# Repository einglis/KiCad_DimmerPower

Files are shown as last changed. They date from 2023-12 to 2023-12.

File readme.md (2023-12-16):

# Dimmer Power Board

A power board for my lounge dimmer project.  Ultimately driven by an Arduino running code in https://github.com/einglis/dimmer.  (And a RaspberyPI providing a UI, and another Arduino receiving Rako wireless commands, both also running code from the same repo.)

Originally based on https://www.instructables.com/Multichannel-Wireless-Light-Dimmer/

At the time of writing, the six live boards have got 5 years of successful operation under their belts.

## Version History
I drew this originally in Eagle, but the committed project is for KiCad.  KiCad seemed to import it just fine and the schematic and board layout look identical to the production parts; the gerbers in the `output/` folder check out too.

All the same, I preserved the bulk of the Eagle files in the `retired/` folder, just in case.  They show signs of sequential-numbering version control...

## Pictures
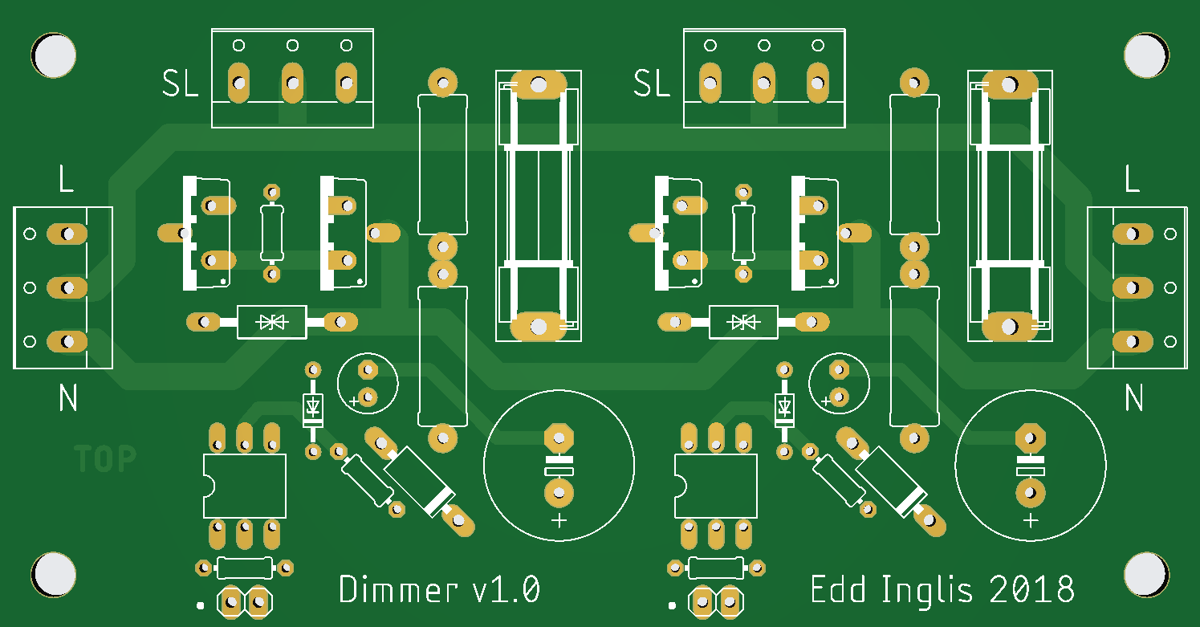
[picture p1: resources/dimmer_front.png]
front

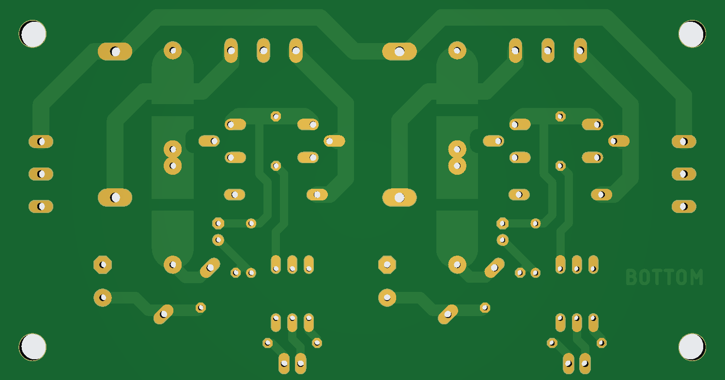
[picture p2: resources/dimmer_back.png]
back


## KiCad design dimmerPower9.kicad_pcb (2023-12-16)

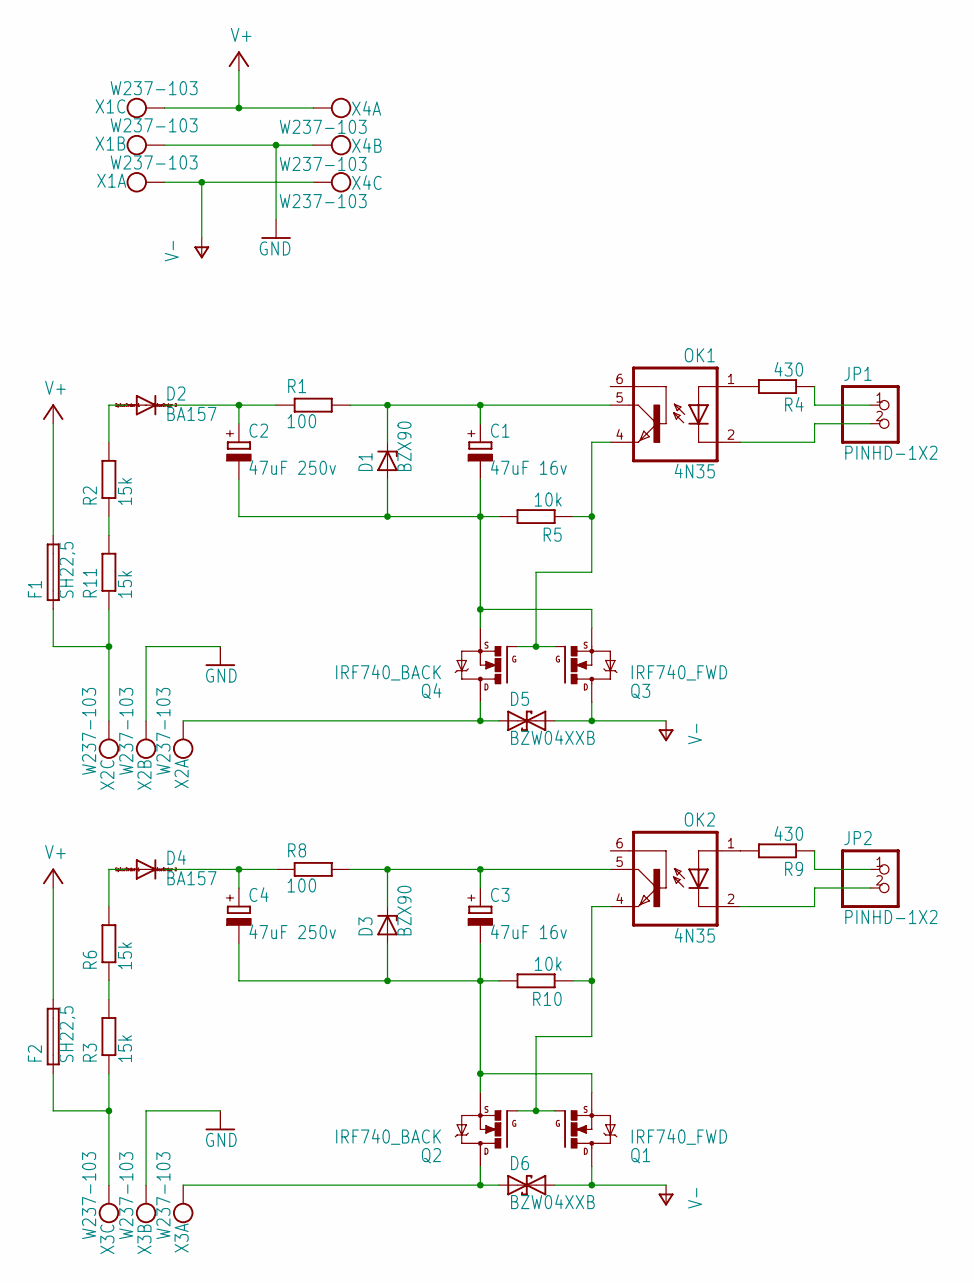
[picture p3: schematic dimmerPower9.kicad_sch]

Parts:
C1, C3: 47uF 16v; E2,5-6
C2, C4: 47uF 250v; E5-13
D1, D3: BZX90; DO34Z7
D2, D4: BA157; P1-10
D5, D6: BZW04XXB; F126Z12
F1, F2: SH22,5
JP1, JP2: PINHD-1X2; 1X02
OK1, OK2: 4N35; DIL06
Q1, Q3: IRF740_FWD; TO220BV_FWD
Q2, Q4: IRF740_BACK; TO220BV_BACK
R1, R8: 100; 0204_7
R2, R3, R6, R11: 15k; P0613_15
R4, R9: 430; 0204_7
R5, R10: 10k; 0204_7
X1, X2, X3, X4: W237-103

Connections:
GND: X1.2, X2.2, X3.2, X4.2
unnamed: C1.-, C2.-, D1.A, Q3.S, Q4.S, R5.2
unnamed: JP1.1, R4.1
unnamed: OK1.1 (A), R4.2
unnamed: JP1.2, OK1.2 (C)
unnamed: F1.1, R11.1, X2.3
unnamed: R3.2, R6.1
unnamed: R2.1, R11.2
unnamed: D2.A, R2.2
unnamed: C2.+, D2.C, R1.1
unnamed: C1.+, D1.C, OK1.5 (COL), R1.2
unnamed: OK1.4 (EMI), Q3.G, Q4.G, R5.1
unnamed: D5.A (1), Q4.D, X2.1
unnamed: D4.A, R6.2
unnamed: C4.+, D4.C, R8.1
unnamed: C3.+, D3.C, OK2.5 (COL), R8.2
unnamed: OK2.1 (A), R9.2
unnamed: D6.A (1), Q2.D, X3.1
unnamed: JP2.1, R9.1
unnamed: JP2.2, OK2.2 (C)
unnamed: OK2.4 (EMI), Q1.G, Q2.G, R10.1
unnamed: C3.-, C4.-, D3.A, Q1.S, Q2.S, R10.2
unnamed: F2.1, R3.1, X3.3
V+: F1.2, F2.2, X1.3, X4.1
V-: D5.C (2), D6.C (2), Q1.D, Q3.D, X1.1, X4.3

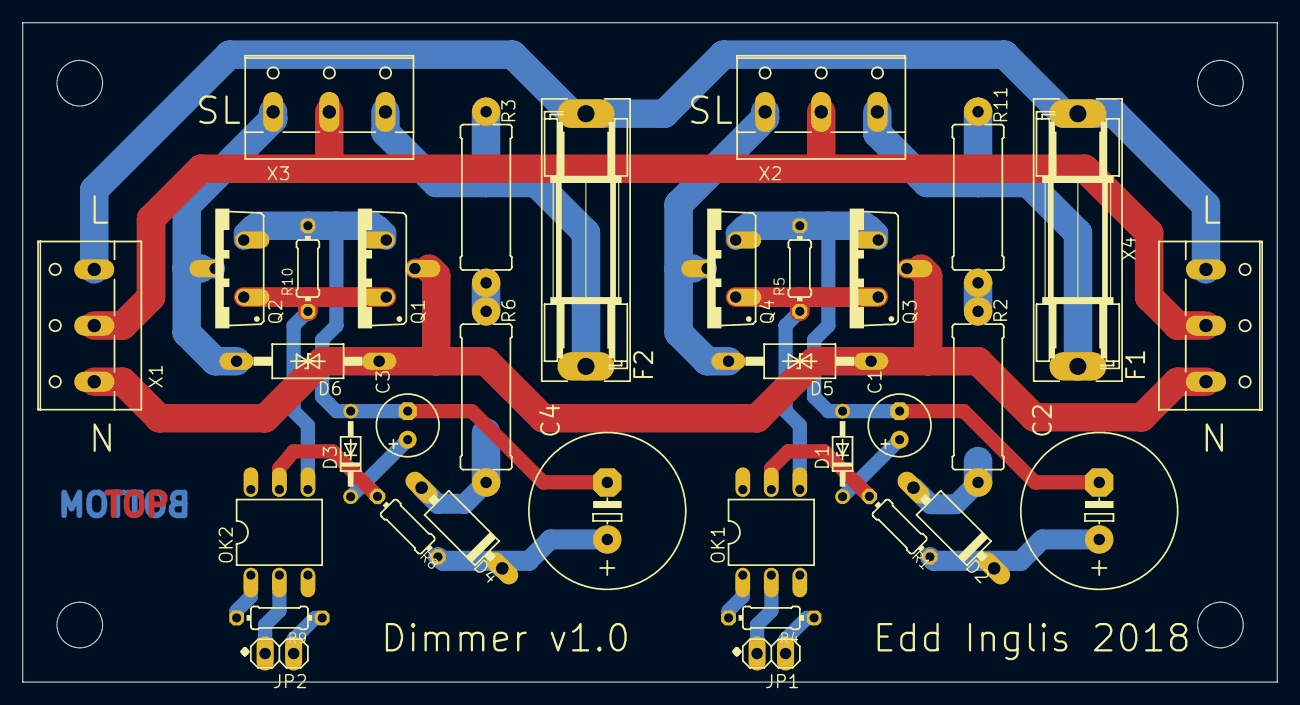
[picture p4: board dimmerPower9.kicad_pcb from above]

Board: 4 copper layers, 111.7 x 58.7 mm, 38 parts (0 on the bottom side), 25 nets.

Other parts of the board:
@HOLE0, @HOLE1, @HOLE2, @HOLE3: (no value)

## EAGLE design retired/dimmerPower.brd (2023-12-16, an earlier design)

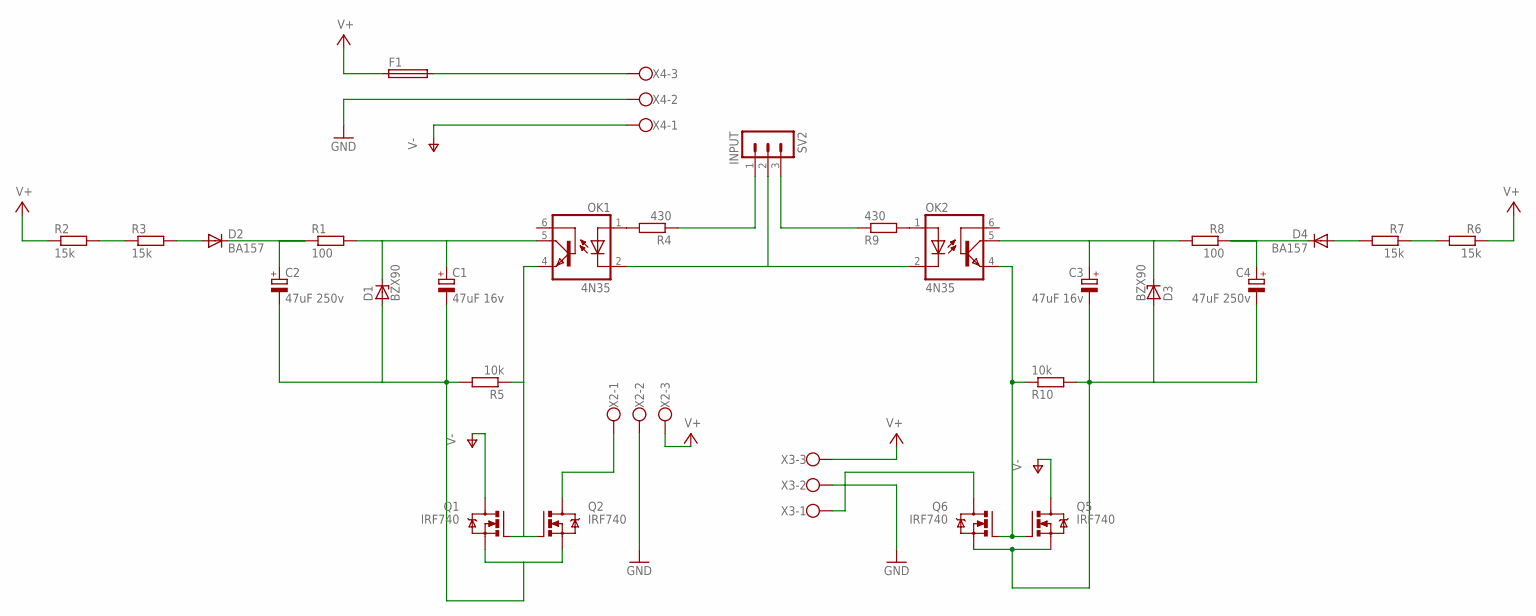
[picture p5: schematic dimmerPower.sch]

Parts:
C1, C3: 47uF 16v; E2,5-6
C2, C4: 47uF 250v; E5-13
D1, D3: BZX90; DO34Z7
D2, D4: BA157; P1-10
F1: SH22,5
OK1, OK2: 4N35; DIL06
Q1, Q2, Q5, Q6: IRF740; TO220BV
R1, R8: 100; 0204/7
R2, R3, R6, R7: 15k; P0613/15
R4, R9: 430; 0204/7
R5, R10: 10k; 0204/7
SV2: INPUT; MA03-1
X2, X3, X4: W237-103

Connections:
GND: X2.2, X3.2, X4.2
unnamed: Q6.D, X3.1
unnamed: OK1.2 (C), OK2.2 (C), SV2.2
unnamed: OK1.1 (A), R4.2
unnamed: C3.-, C4.-, D3.A, Q5.S, Q6.S, R10.2
unnamed: C1.-, C2.-, D1.A, Q1.S, Q2.S, R5.2
unnamed: R2.2, R3.1
unnamed: D2.A, R3.2
unnamed: C2.+, D2.C, R1.1
unnamed: C1.+, D1.C, OK1.5 (COL), R1.2
unnamed: R4.1, SV2.1
unnamed: Q2.D, X2.1
unnamed: R6.2, R7.1
unnamed: D4.A, R7.2
unnamed: C4.+, D4.C, R8.1
unnamed: C3.+, D3.C, OK2.5 (COL), R8.2
unnamed: R9.1, SV2.3
unnamed: OK2.1 (A), R9.2
unnamed: OK1.4 (EMI), Q1.G, Q2.G, R5.1
unnamed: OK2.4 (EMI), Q5.G, Q6.G, R10.1
V+: F1.1, R2.1, R6.1, X2.3, X3.3
V+1: F1.2, X4.3
V-: Q1.D, Q5.D, X4.1

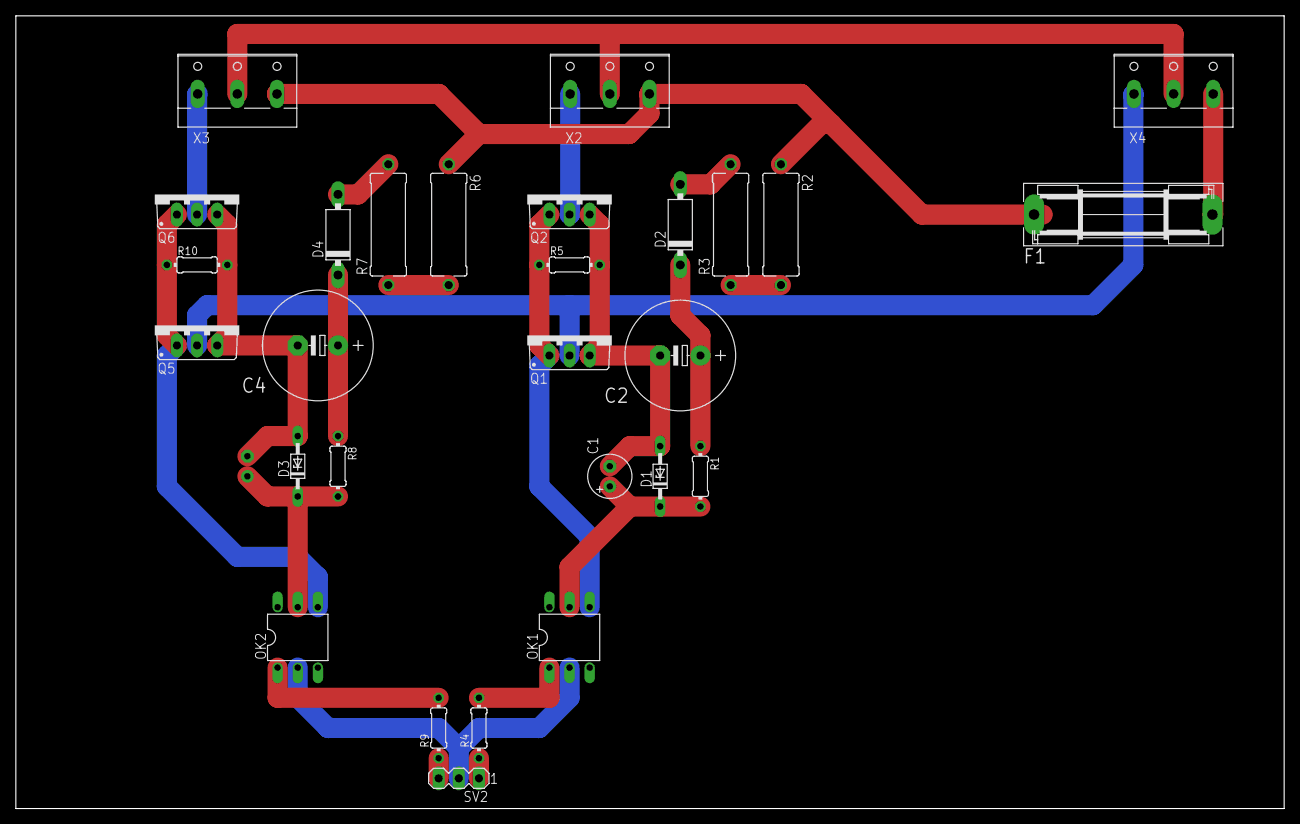
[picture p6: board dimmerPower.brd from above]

Board: 2 copper layers, 160.0 x 100.0 mm, 29 parts (1 on the bottom side), 23 nets.

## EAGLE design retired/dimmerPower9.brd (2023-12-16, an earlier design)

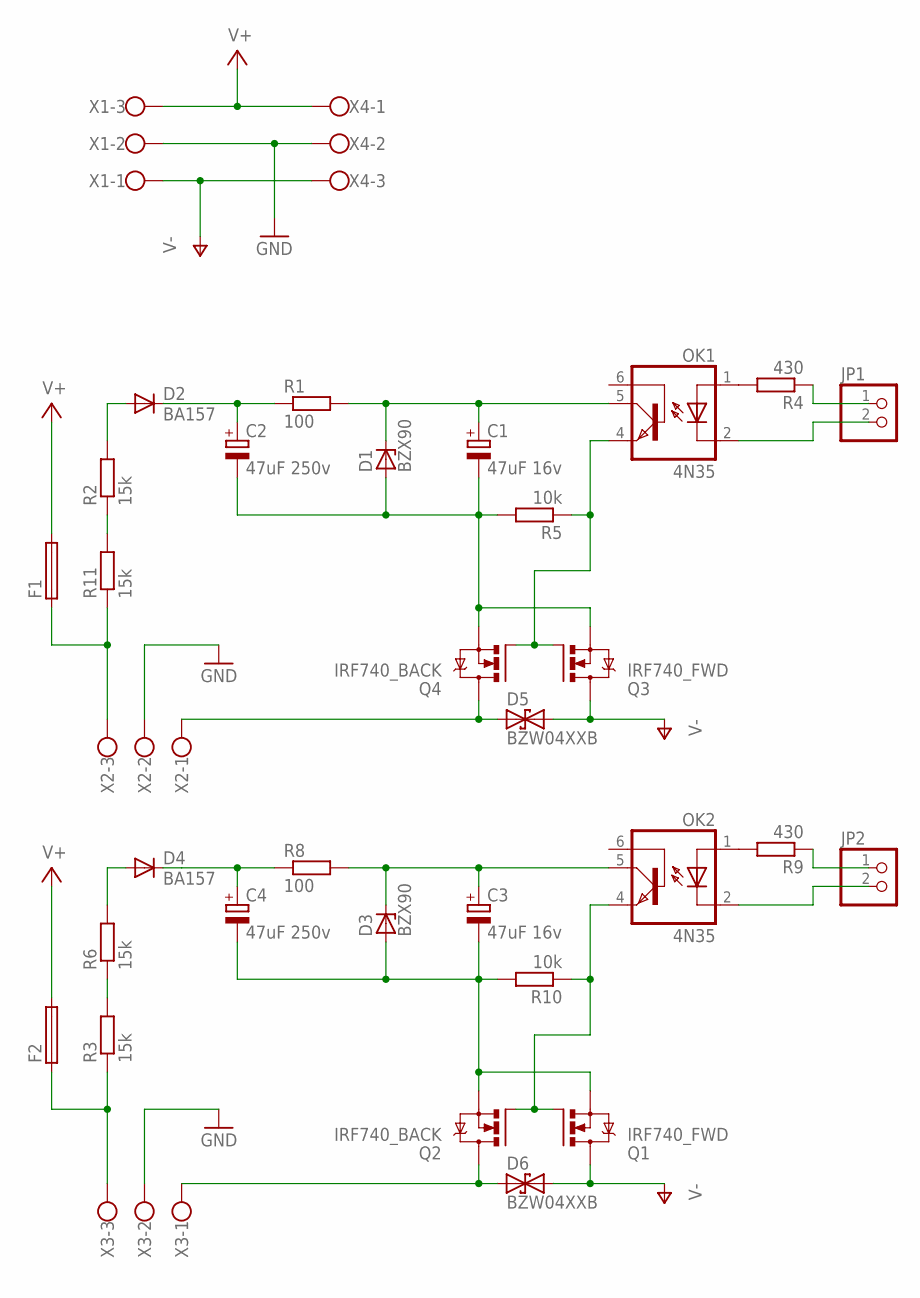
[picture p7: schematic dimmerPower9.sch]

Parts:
C1, C3: 47uF 16v; E2,5-6
C2, C4: 47uF 250v; E5-13
D1, D3: BZX90; DO34Z7
D2, D4: BA157; P1-10
D5, D6: BZW04XXB; F126Z12
F1, F2: SH22,5
JP1, JP2: PINHD-1X2; 1X02
OK1, OK2: 4N35; DIL06
Q1, Q3: IRF740_FWD; TO220BV_FWD
Q2, Q4: IRF740_BACK; TO220BV_BACK
R1, R8: 100; 0204/7
R2, R3, R6, R11: 15k; P0613/15
R4, R9: 430; 0204/7
R5, R10: 10k; 0204/7
X1, X2, X3, X4: W237-103

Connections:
GND: X1.2, X2.2, X3.2, X4.2
unnamed: C1.-, C2.-, D1.A, Q3.S, Q4.S, R5.2
unnamed: JP1.1, R4.1
unnamed: OK1.1 (A), R4.2
unnamed: JP1.2, OK1.2 (C)
unnamed: F1.1, R11.1, X2.3
unnamed: R3.2, R6.1
unnamed: R2.1, R11.2
unnamed: D2.A, R2.2
unnamed: C2.+, D2.C, R1.1
unnamed: C1.+, D1.C, OK1.5 (COL), R1.2
unnamed: OK1.4 (EMI), Q3.G, Q4.G, R5.1
unnamed: D5.A (1), Q4.D, X2.1
unnamed: D4.A, R6.2
unnamed: C4.+, D4.C, R8.1
unnamed: C3.+, D3.C, OK2.5 (COL), R8.2
unnamed: OK2.1 (A), R9.2
unnamed: D6.A (1), Q2.D, X3.1
unnamed: JP2.1, R9.1
unnamed: JP2.2, OK2.2 (C)
unnamed: OK2.4 (EMI), Q1.G, Q2.G, R10.1
unnamed: C3.-, C4.-, D3.A, Q1.S, Q2.S, R10.2
unnamed: F2.1, R3.1, X3.3
V+: F1.2, F2.2, X1.3, X4.1
V-: D5.C (2), D6.C (2), Q1.D, Q3.D, X1.1, X4.3

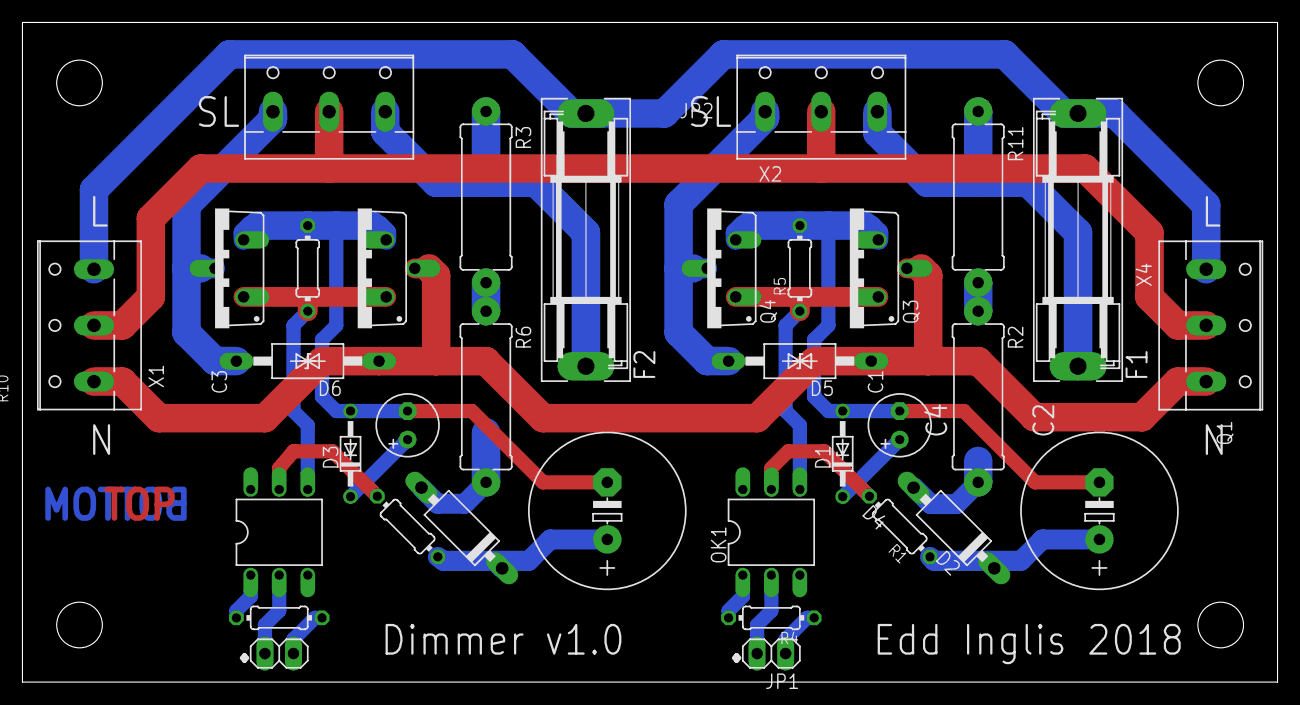
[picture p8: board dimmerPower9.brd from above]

Board: 2 copper layers, 111.7 x 58.7 mm, 34 parts (0 on the bottom side), 25 nets.

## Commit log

2023-12-16 adding gerbers
2023-12-16 This was originally drawn with Eagle; out of paranoia, I'm committing all the files I have from that era, though the main KiCad project looks exactly like that which was produced
    [dimmerPower.brd, dimmerPower.sch, dimmerPower2.brd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]
